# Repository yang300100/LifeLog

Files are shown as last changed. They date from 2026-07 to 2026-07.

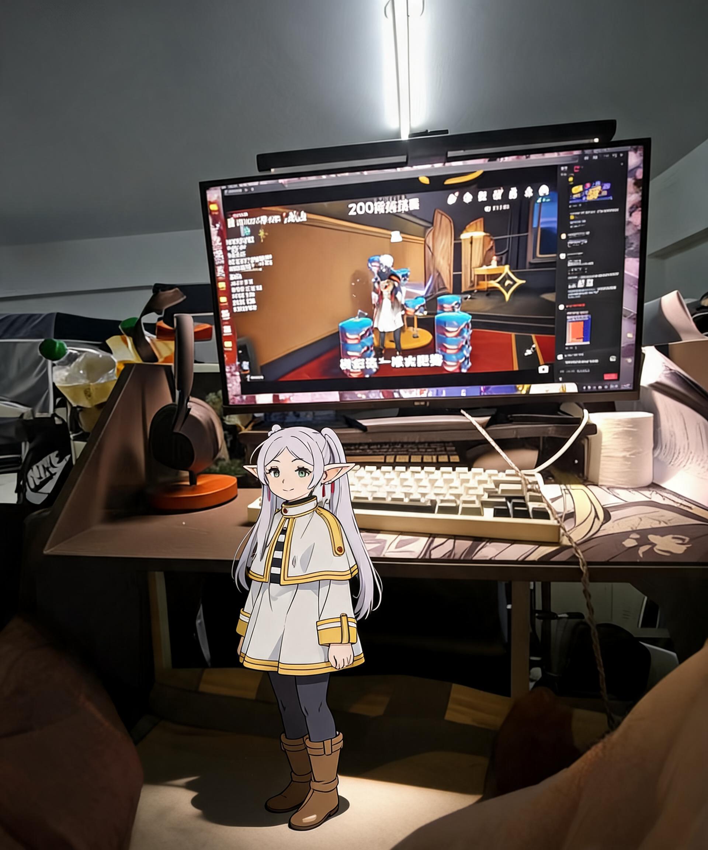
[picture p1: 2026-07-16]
prototype/e2e_output/final_result_20260630_160802.png

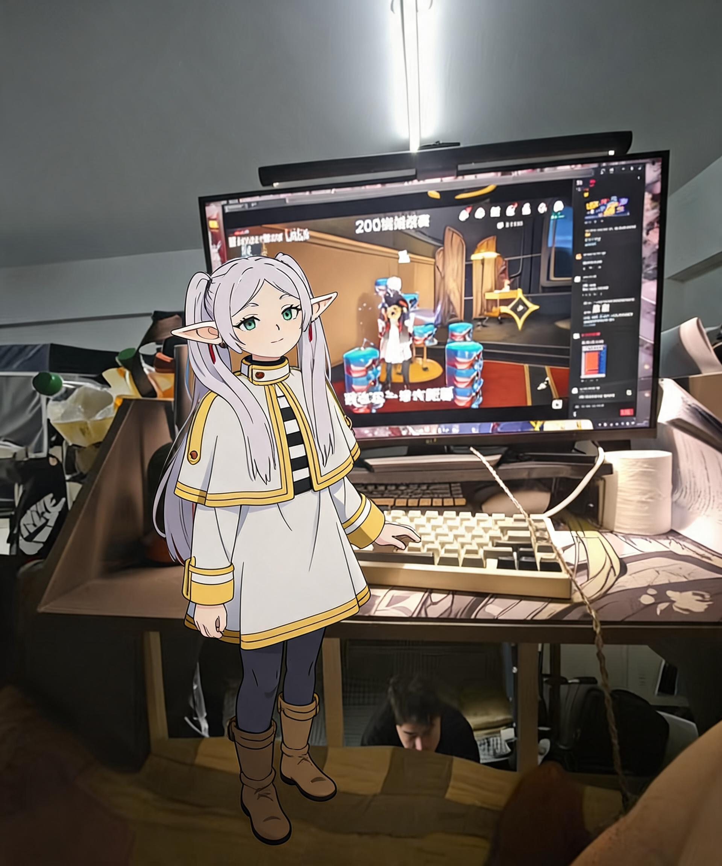
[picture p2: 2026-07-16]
prototype/e2e_output/final_result_20260630_160603.png

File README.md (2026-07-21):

# LifeLog

一款可穿戴的别针式生活记录摄像头。定时拍摄短视频片段，通过 BLE 同步到 Android 手机，利用云端 AI 分析行为并生成自然语言日报。同时提供 AI 陪伴模式，支持个性化风格照片生成。

A wearable lifelog camera in a brooch form factor. Captures short video clips at regular intervals, syncs to an Android phone via BLE, and generates natural-language daily journals using cloud AI — including an AI Companion mode for personalized stylized photo generation.

## 系统架构 / Architecture

```
ESP32-CAM （固件）             Android App               云端 AI
+------------------+       +-------------------+       +----------+
| OV3660 摄像头     |       | BLE 同步服务       |       | Kimi API |
| MJPEG 录制        | --BLE--> 文件接收          | --HTTP--> （文本）  |
| SD 卡存储         |       | 时间轴 UI          |       | Seedream |
| Deep Sleep + 踢狗  |       | AI 分析引擎        |       | （图像）  |
+------------------+       | 陪伴模式           |       +----------+
                           | 存储管理           |
                           +-------------------+
                                  |
                           +-------------------+
                           | YOLOv8n (NCNN)    |
                           | 端侧人像分割        |
                           +-------------------+
```

## 核心功能 / Key Features

- **定时拍摄 / Interval Capture** -- ESP32-CAM + OV3660 定时录制 MJPEG 视频片段（默认 QXGA 2048×1536，5 秒，5 分钟间隔）。
- **日期时间文件名 / Date-Time Filenames** -- 手机同步时间基准后，视频文件名自动使用录制日期时间（如 `20260721_143025.mjpg`），无需依赖序号。
- **BLE 文件传输 / BLE File Transfer** -- 窗口化 GATT 推送 + GATT Read 回退，支持断点续传和分页文件列表。
- **AI 日报生成 / AI Daily Reports** -- 全帧提取 → 分批发送 → Kimi API 视觉分析 → 结构化自然语言日报。
- **AI 陪伴模式 / AI Companion Mode** -- 端侧 YOLOv8n 分割检测人物，调用 Seedream API 进行局部重绘，将用户融入风格化场景。
- **RPG 实时模式 / RPG Realtime Mode** -- 基于角色的互动模式，实时活动记录与 AI 驱动叙事响应。
- **存储管理 / Storage Management** -- 按日期查看存储占用，单独/按天/全部删除视频源文件，保留数据库记录和分析结果。
- **3D 打印外壳 / 3D Printed Enclosure** -- OpenSCAD 设计的定制外壳，带挂绳孔，支持标准 FDM 打印机。

## 仓库结构 / Repository Structure

```
firmware/lifelog/         ESP32-CAM 固件 (Arduino / C++)
    lifelog.ino             主程序，含状态机 + PB0A 踢狗 + 时间同步
    camera.cpp/h            OV3660 拍摄与 MJPEG 编码
    sd_storage.cpp/h        SD 卡读写、日期文件名生成、文件索引
    ble_service.cpp/h       NimBLE GATT 服务端、窗口化文件传输
    configuration.cpp/h     运行时设置持久化（锐度/对比度/饱和度等）
    timebase.cpp/h          时间基准管理（手机同步 → 本地计时）
    config.h                编译期功能开关、踢狗间隔、默认参数
    camera_pins.h           AI-Thinker ESP32-CAM 引脚映射

android/                  Android App (Kotlin / Jetpack Compose)
    app/src/main/java/com/lifelog/camera/
        ai/                 AI 分析、分批发送、关键帧提取、陪伴流水线
        ble/                BLE 文件同步客户端、设备配置同步
        data/               Room 数据库、存储统计、数据仓库
        di/                 Hilt 依赖注入模块
        ui/timeline/        时间轴主页 & 陪伴画廊
        ui/report/          日报生成与查看
        ui/realtime/        RPG 角色实时模式
        ui/settings/        API 配置、设备设置、存储管理
        util/               崩溃日志、图像工具

enclosure/                OpenSCAD 外壳设计
    Lifelog_Case.scad       3D 打印两片式外壳

prototype/                Python 探索性脚本
    YOLO 分割、Seedream 融合测试、
    陪伴流水线原型验证
```

## 硬件规格 / Hardware

| 组件 / Component | 规格 / Specification |
|---|---|
| MCU | ESP32 (AI-Thinker ESP32-CAM) |
| 摄像头 / Camera | OV3660 (2048×1536 QXGA MJPEG) 或 OV2640 (1600×1200 UXGA) |
| 存储 / Storage | MicroSD 卡 (1-bit SD 模式) |
| 电池 / Battery | 3.7V 800mAh 锂聚合物 (402030) |
| 电源模块 / Power | PB0A 充放电一体模块（充电 + 升压5V + 电池保护 + 轻载自动断电） |
| 外壳 / Enclosure | 3D 打印 PLA/PETG，45x60x15mm |

### 接线说明 / Wiring

```
PB0A 模块           ESP32-CAM
  5V  ───────────→  5V
  GND ───────────→  GND
  BAT+ ─────────→  电池红线
  BAT- ─────────→  电池黑线
```

仅需 4 根线，全部使用成品模块，零贴片焊接。PB0A 模块通过 USB-C 充电（兼容 C-to-C 线缆），自带 4 级电量指示。

### PB0A 踢狗机制 / PB0A Keep-Alive

PB0A 充放电芯片会在负载电流 < 50mA 持续 > 32 秒时自动断电。Deep Sleep 时 ESP32 仅 4-6mA，会触发断电。

解决方案：每 25 秒唤醒一次 ESP32（启动电流 ~70mA 踢回 PB0A 计时器），踢狗唤醒时仅做最小化启动（串口 + 200ms 延迟），不初始化 SD/摄像头/BLE，功耗极低。

### 引脚约束 / Pin Constraints

- **GPIO4** -- 与 SD 卡 DATA1 冲突，LED 闪光灯永久禁用。
- **GPIO12** -- Strapping pin，启动时必须保持低电平或浮空。
- **GPIO33** -- 板载红色 LED（低电平点亮）+ 电池 ADC 分时复用。
- Deep Sleep 电流约 4-6mA（含 PB0A 升压模块静态功耗）。

## 固件编译 / Firmware Build

在 Arduino IDE 2.x 中打开 `firmware/lifelog/` 项目。

- **开发板 / Board**: AI-Thinker ESP32-CAM
- **分区方案 / Partition Scheme**: No OTA (Large APP) -- 至少 3MB 程序空间
- **波特率 / Baud Rate**: 115200
- **依赖库 / Required Libraries**: `esp_camera` (Espressif Systems)、NimBLE

### 编译开关 / Build Flags

在 `config.h` 中定义：

| 开关 / Flag | 用途 / Purpose |
|---|---|
| `WITH_SLEEP` | 拍摄间隔期间进入 Deep Sleep 省电 |
| `WITH_BLE` | 启用 BLE 广播与 GATT 文件传输 |
| `WITH_VIDEO` | 启用 MJPEG 视频录制到 SD 卡 |
| `WITH_STATUS_LED` | 启用 GPIO33 状态指示灯 |
| `WITH_AUTO_FLASH` | 暗光自动闪光灯（AEC 曝光行数阈值） |

**有意禁用的开关**: `WITH_FLASH`、`WITH_SD_4BIT`、`WITH_CAM_PWDN`、`WITH_SETUP_MODE_BUTTON`、`WITH_EVIL_CAM_PWR_SHUTDOWN`（简化硬件无需外部 MOSFET）。

### 可配置参数 / Configurable Parameters

通过 Android App 设置页面远程配置，写入 SD 卡 `camera.cfg`，下周期生效：

| 参数 / Parameter | 默认值 / Default | 范围 / Range |
|---|---|---|
| 拍摄间隔 / Interval | 300s (5min) | 60s - 3600s |
| 视频时长 / Duration | 5s | 1s - 30s |
| 分辨率 / Resolution | QXGA (2048×1536) | QVGA - QXGA |
| JPEG 质量 / Quality | 12 | 10 - 30 |
| 帧率 / FPS | 3 | 1 - 10 |
| 锐度 / Sharpness | +1 | -2 ~ +2 |
| 对比度 / Contrast | 0 | -2 ~ +2 |
| 饱和度 / Saturation | 0 | -2 ~ +2 |
| 闪光灯阈值 / Flash Threshold | 150 行 | 50 - 300 |
| BLE 广播窗口 / BLE Timeout | 30s | 30s - 600s |
| BLE 设备名 / Device Name | lifelog-cam | 最长 30 字符 |

### 烧录步骤 / Flashing

1. 连接 USB 转 TTL 适配器：RX-TX、TX-RX、GND-GND、5V-5V。
2. 将 IO0 与 GND 短接进入下载模式。
3. 上电，从 Arduino IDE 上传。
4. 移除 IO0-GND 短接，按复位键运行。

## Android App 编译 / Android App Build

在 Android Studio 中打开 `android/` 目录。

- **最低 SDK / Min SDK**: 26 (Android 8.0)
- **目标 SDK / Target SDK**: 34
- **NDK**: 30.0.14904198 (arm64-v8a)
- **主要依赖 / Key Dependencies**: Jetpack Compose, Hilt, Room, OkHttp, NCNN (native)

```bash
cd android
./gradlew assembleDebug
```

## 配置 / Configuration

首次开机时若 SD 卡无配置文件，设备进入设置模式并持续 BLE 广播，通过 Android App 进行配置。

### 时间同步 / Time Sync

ESP32 无实时时钟。每次手机 BLE 连接时自动发送当前本地时间给固件，固件据此计算 `时间基准 = 手机时间 - 开机计时器`。录制时用 `基准 + 计时器` 反算真实录制时刻，生成日期时间文件名。

RES/断电后 RTC 内存丢失，固件启动时先跑一个 30 秒 BLE 窗口获取最新时间。

### 存储管理 / Storage Management

设置 → 存储管理：按日期查看视频源文件占用，可单独/按天/全部删除 .mjpg 和 .mp4 文件。数据库记录、AI 分析结果、RPG 角色数据不受影响。

On first boot without a configuration file on the SD card, the device enters setup mode and broadcasts BLE continuously. Use the Android app to configure the parameters above.

## AI 后端 / AI Backend

Android App 支持在设置中配置多种 AI 后端：

| 用途 / Use | 后端 / Backend | 说明 / Notes |
|---|---|---|
| 文本分析 / Text Analysis | Kimi API | OpenAI 兼容接口，用于场景分析、日报生成、陪伴提示词 |
| 图像生成 / Image Generation | Seedream API | 用于陪伴模式的局部重绘 |
| 端侧推理 / On-Device | YOLOv8n (NCNN) | 陪伴流水线中的人像分割 |

API 密钥和接口地址在 App 运行时通过设置界面配置，存储在 Android SharedPreferences 中，源代码不含任何密钥。

API keys and endpoint URLs are configured at runtime via the app settings and stored in Android SharedPreferences. No keys are included in the source code.

## 开源协议 / License

本项目仅供个人使用，保留所有权利。

This project is for personal use. All rights reserved.

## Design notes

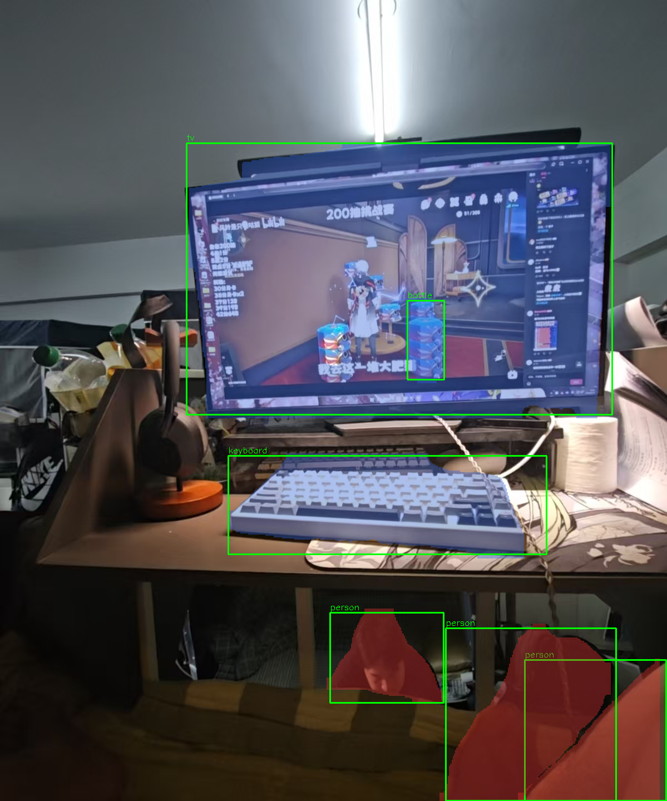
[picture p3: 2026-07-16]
prototype/e2e_output/yolo_seg_20260630_160802.png

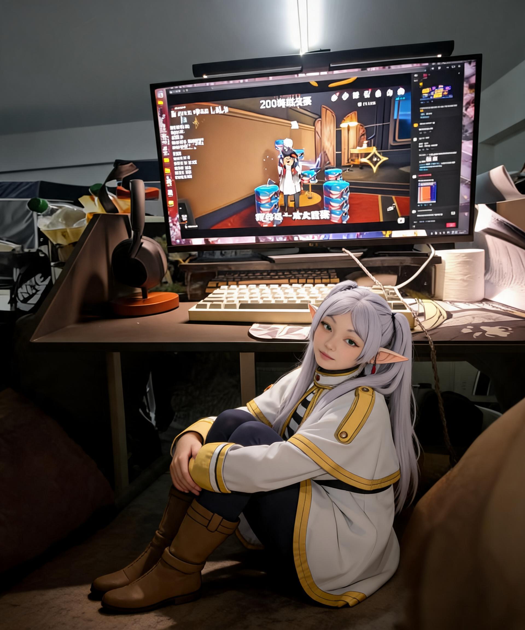
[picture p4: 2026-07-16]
prototype/seedream_output/showcase_B_sitting_area_20260630_154001.png

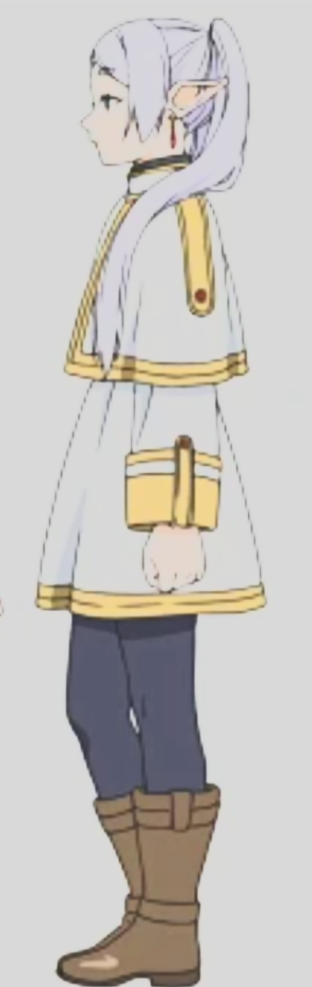
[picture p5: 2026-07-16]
prototype/ref_desktop_02.png

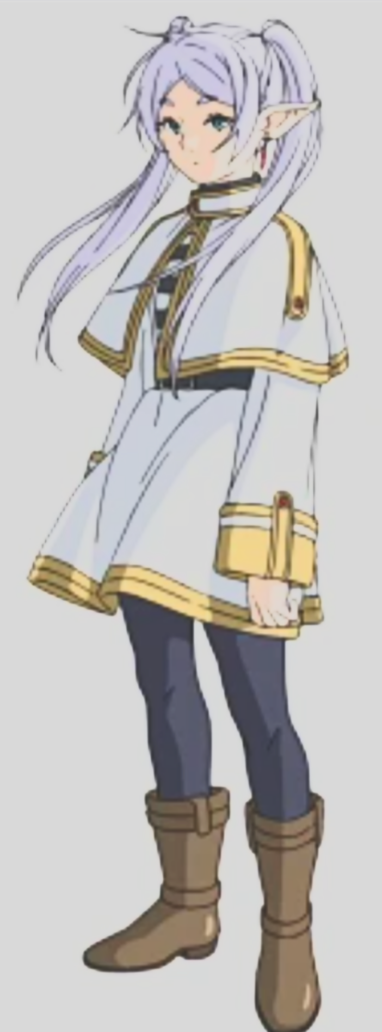
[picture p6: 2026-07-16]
prototype/ref_03.png

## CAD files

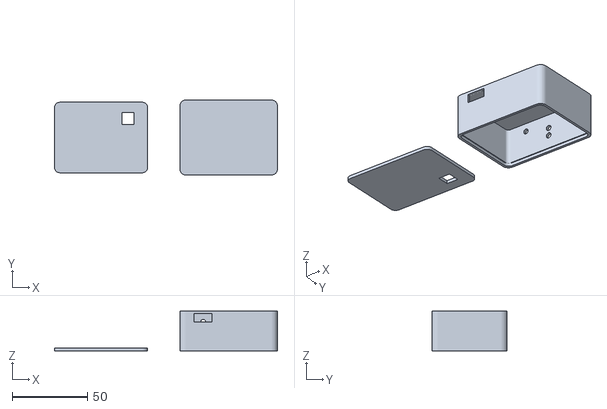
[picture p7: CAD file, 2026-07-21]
enclosure/Lifelog_Case_v2.stl
148.5 x 50.0 x 26.6

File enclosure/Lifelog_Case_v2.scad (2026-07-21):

// LifeLog Camera 外壳 v2
// 硬件: 电池(长36宽27高22) + ESP32(长43宽27高23)
// 按钮: 3mm, 位于电池顶部; USB-C: 位于电池底部

battery_w  = 27;   // 电池宽
battery_h  = 22;   // 电池高
battery_d  = 36;   // 电池长

esp32_w    = 27;   // ESP32宽
esp32_h    = 23;   // ESP32高
esp32_d    = 43;   // ESP32长

gap        = 4; clearance  = 1.5;
wall       = 1.8; round_r    = 4;

// 内部尺寸
inner_w = battery_w + gap + esp32_w + clearance * 2;  // 长61
inner_d = 23;           // 高23
inner_h = max(battery_d, esp32_d) + clearance * 2;  // 宽46

shelf_wall = 2; shelf_h = 5;
cover_ledge = 1.5; cover_d = 2;

// 外部尺寸
body_w = inner_w + 2 * shelf_wall;  // 长65
body_h = shelf_wall + inner_h + cover_d;  // 高27
body_d = inner_d + 2 * wall;         // 宽50

// 元件位置
clo = shelf_wall;
elo = clo + battery_w + gap;
cbo = shelf_wall + (inner_h - battery_h) / 2;  // 电池Y居中
ebo = shelf_wall + (inner_h - esp32_h) / 2;    // ESP32 Y居中
cdo = clearance;
edo = clearance;

cam_sz = 8;
cam_cx = elo + esp32_w / 2;
cam_top_margin = cam_sz + (shelf_h - cover_d);
cam_cy = body_h - cover_ledge - cam_top_margin - cam_sz/2;

btn_d = 3.2; btn_h = 11;
btn_cx = clo + battery_w / 2;
btn_cz = cdo + battery_d / 2;

usb_w = 10; usb_h = 4;
usb_cx = clo + battery_w / 2;
usb_cz = cdo + battery_d / 2 + 2.6;

lanyard_d = 3.5; lanyard_num = 2; lanyard_sp = 5;
lanyard_at_x = body_w / 2;
lanyard_at_z = body_d / 2;
lanyard_dir = "z";

cover_w = body_w - 2 * cover_ledge;
cover_h = body_h - 2 * cover_ledge;
cover_r = round_r - 0.5;

module rb(w, h, d, r) {
    hull() for(x=[r, w-r]) for(y=[r, h-r])
        translate([x, y, 0]) cylinder(r=r, h=d, $fn=32);
}

module front_shell() {
    difference() {
        color("LightSteelBlue", 0.9)
        translate([cover_ledge, cover_ledge, 0])
            rb(cover_w, cover_h, cover_d, cover_r);
        translate([cam_cx, cam_cy, -1])
            cube([cam_sz, cam_sz, cover_d + 2]);  // 去掉center=true, 从Z=-1贯穿到Z=3
    }
}

module back_shell() {
    bd = body_d;
    difference() {
        color("LightSlateGray", 0.9) rb(body_w, body_h, bd, round_r);
        hull() {
            translate([shelf_wall, shelf_wall, cover_d])
                rb(inner_w, inner_h, 0.1, round_r - wall);
            translate([wall, wall, shelf_h])
                rb(body_w - 2*wall, body_h - 2*wall, 0.1, round_r - wall);
        }
        translate([wall, wall, shelf_h])
            rb(body_w - 2*wall, body_h - 2*wall, bd - wall - shelf_h, round_r - wall);
        translate([cover_ledge, cover_ledge, 0])
            rb(cover_w, cover_h, cover_d, cover_r);
        btn_ty = cbo + battery_h;
        btn_ch = body_h - btn_ty;
        translate([btn_cx, body_h, btn_cz])
            rotate([90, 0, 0]) cylinder(d=btn_d, h=wall + 2, $fn=48);
        translate([btn_cx, btn_ty, btn_cz])
            rotate([90, 0, 0])
                difference() {
                    cylinder(d=btn_d + 3, h=btn_ch, $fn=48);
                    translate([0, 0, -1])
                        cylinder(d=btn_d, h=btn_ch + 2, $fn=48);
                }
        translate([usb_cx, wall + (wall + 3)/2, usb_cz])
            cube([usb_w, wall + 3, usb_h], center=true);
        translate([usb_cx, wall - 2, usb_cz])
            cube([usb_w + 2, 4, usb_h + 1.5], center=true);
        if (lanyard_num == 1) {
            translate([lanyard_at_x, body_h, lanyard_at_z])
                rotate([90, 0, 0]) cylinder(d=lanyard_d, h=wall + 2, $fn=32);
        } else {
            if (lanyard_dir == "x") {
                for (x = [lanyard_at_x - lanyard_sp/2, lanyard_at_x + lanyard_sp/2])
                    translate([x, body_h, lanyard_at_z])
                        rotate([90, 0, 0]) cylinder(d=lanyard_d, h=wall + 2, $fn=32);
            } else {
                for (z = [lanyard_at_z - lanyard_sp/2, lanyard_at_z + lanyard_sp/2])
                    translate([lanyard_at_x, body_h, z])
                        rotate([90, 0, 0]) cylinder(d=lanyard_d, h=wall + 2, $fn=32);
            }
        }
    }
}

translate([0, 0, 0]) front_shell();
translate([body_w + 20, 0, 0]) back_shell();
// front_shell();
// back_shell();

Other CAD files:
enclosure/Lifelog_Case.scad

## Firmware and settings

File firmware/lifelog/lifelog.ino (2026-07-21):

// LifeLog Camera — 随身行为记录摄像头固件
//
// 状态机:
//   冷启动 → 检测 SD 卡配置文件
//     ├── 无 camera.cfg → 设置模式 (BLE 持续广播，等手机配置)
//     └── 有 camera.cfg → 正常循环:
//           Wake → Init Camera → Capture Video → SD 存储
//           → BLE 广播窗口 → Camera Off → Deep Sleep
//
// Phase 1+2: 录制循环 + BLE GATT 文件传输

#include "config.h"
#include "camera_pins.h"
#include "camera.h"
#include "sd_storage.h"
#include "configuration.h"
#include "ble_service.h"
#include "timebase.h"
#include "SD_MMC.h"
#include "esp_sleep.h"
#include "esp_timer.h"
#include "driver/rtc_io.h"
#include "driver/gpio.h"
#include <stdio.h>

// ── 板载状态 LED ──
// ESP32-CAM 红色 LED（GPIO33）：低电平点亮（阴极接 GPIO，阳极接 3.3V）
#ifdef WITH_STATUS_LED
void led_on()  { pinMode(33, OUTPUT); digitalWrite(33, LOW);  }  // LOW = 亮
void led_off() { pinMode(33, OUTPUT); digitalWrite(33, HIGH); }  // HIGH = 灭
void led_init() {
    gpio_set_direction(GPIO_NUM_33, GPIO_MODE_OUTPUT);
    gpio_set_level(GPIO_NUM_33, HIGH);  // 初始灭
}
#else
void led_on()  {}
void led_off() {}
void led_init() {}
#endif

// RTC 内存变量 — Deep Sleep 唤醒后保留
RTC_DATA_ATTR uint32_t boot_count = 0;
RTC_DATA_ATTR uint32_t restart_count = 0;  // 防止无限重启循环
RTC_DATA_ATTR uint8_t  kicks_remaining = 0; // PB0A 踢狗剩余次数（0=正常录制）
RTC_DATA_ATTR uint32_t rtc_expected_sleep_ms = 0; // 本次期望休眠时长（ms），醒来后补偿时间基准
RTC_DATA_ATTR uint64_t rtc_esp_before_sleep = 0;  // 休眠前 esp_timer ms，用于计算实际前进量

AppConfig g_cfg;

// ── 踢狗版 Deep Sleep ──
// PB0A 充放电芯片：负载 < 50mA 持续 > 32s 自动断电。
// Deep Sleep 时 ESP32 只吃 4-6mA → 会被 PB0A 断电。
// 解决方案：空闲 > 30s 时，分段睡眠（每 25s 唤醒一次），
// 启动时的 ~70mA 电流脉冲把 PB0A 的 32s 计时器踢回去。
static void enter_deep_sleep() {
    uint32_t elapsed = millis();  // 本次启动已用时间
    uint32_t interval = g_cfg.interval;

    // 计算空闲时间
    uint32_t idle_ms;
    if (interval > elapsed) {
        idle_ms = interval - elapsed;
    } else {
        // 本次耗时超过了间隔（BLE 连太久等极端情况），至少睡 1 秒
        idle_ms = 1000;
    }

    // 释放摄像头资源
    camera_power_off();
    delay(200);  // SD 缓存落盘
    SD_MMC.end();

    // 记录休眠前状态（醒来后 timebase 用这两个值判断是否需要补偿）
    rtc_expected_sleep_ms = idle_ms;
    rtc_esp_before_sleep = (uint64_t)(esp_timer_get_time() / 1000);

    if (idle_ms <= KICK_MIN_IDLE_MS) {
        // 空闲短，PB0A 32s 计时器不会触发，直接睡满
        Serial.printf("[SLEEP] 空闲 %u ms ≤ 30s, 不踢狗, 直接睡\n", idle_ms);
        esp_sleep_enable_timer_wakeup((uint64_t)idle_ms * 1000ULL);
        kicks_remaining = 0;
    } else {
        // 空闲长，需要分段踢狗
        uint8_t kicks = (uint8_t)(idle_ms / KICK_INTERVAL_MS);
        if (kicks > 30) kicks = 30;  // 安全帽
        kicks_remaining = kicks;
        Serial.printf("[SLEEP] 空闲 %u ms → %u 次踢狗, 间隔 %u ms\n",
                      idle_ms, kicks, KICK_INTERVAL_MS);
        esp_sleep_enable_timer_wakeup((uint64_t)KICK_INTERVAL_MS * 1000ULL);
    }

    Serial.flush();
    esp_deep_sleep_start();
}

// ── 录制并存储一段视频 ──
static bool record_clip(uint32_t clip_id) {
    char filepath[40];  // /sdcard/YYYYMMDD_HHMMSS.mjpg = 35 + \0

    // 生成文件名：通过 sd_make_filename 与 sd_next_filename 保证格式一致
    uint64_t record_epoch_ms = 0;
    if (timebase_is_valid()) record_epoch_ms = timebase_now_ms();
    else record_epoch_ms = (uint64_t)(esp_timer_get_time() / 1000);
    sd_make_filename(clip_id, record_epoch_ms, filepath, sizeof(filepath));

    led_on();  // 录制中红灯常亮
    Serial.printf("[REC] 录制 %s (%u ms @ %u fps)...\n",
                  filepath, g_cfg.video_duration, g_cfg.video_fps);

    int frames = camera_capture_video(filepath,
                                      g_cfg.video_duration,
                                      g_cfg.video_fps);

    if (frames < 0) {
        Serial.printf("[ERR] 录制失败 code=%d，删除残缺文件\n", frames);
        remove(filepath);
        return false;
    }

    Serial.printf("[REC] 完成: %d 帧\n", frames);
    led_off();

    // 写入 ID→时间戳 映射（供 sd_next_filename 反查日期文件名 + BLE age 计算）
    if (record_epoch_ms > 0) {
        sd_clip_ts_write(clip_id, record_epoch_ms);
        Serial.printf("[TS-WRITE] clip_%06u → %s\n",
                      clip_id, filepath + 8);  // 跳过 "/sdcard/" (8字符)
    } else {
        // 无时间基准：仍用 esp_timer 记录相对时刻（BLE 列表需要 age 字段）
        uint64_t now_ms = (uint64_t)(esp_timer_get_time() / 1000);
        sd_clip_ts_write(clip_id, now_ms);
        Serial.printf("[TS-WRITE] clip_%06u → esp_timer=%llu ms\n",
                      clip_id, (unsigned long long)now_ms);
    }

    // 更新 SD 卡索引
    if (!sd_index_update_last_id(clip_id)) {
        Serial.println("[ERR] 更新 index.txt 失败");
        return false;
    }

    return true;
}

// ── 设置模式 ──
static void enter_setup_mode() {
    Serial.println("[SETUP] 首次启动 — 自动生成默认配置...");

    config_save("/sdcard/camera.cfg", g_cfg);
    Serial.println("[SETUP] 已生成默认 camera.cfg");
    Serial.printf("[SETUP] 2 秒后开始正常循环...\n");
    delay(2000);
}

// ── 一次性清理旧文件 ──
static void cleanup_old_files() {
    // 检查清理标记文件，已清理过则跳过
    FILE *flag = fopen("/sdcard/.cleanup_done", "r");
    if (flag) { fclose(flag); return; }

    Serial.println("[CLEAN] 检测到首次启动，清理 SD 卡旧文件...");
    // 删除所有旧 clip 文件
    for (uint32_t id = 1; id <= 100; id++) {
        char fname[40];
        sd_next_filename(id, fname, sizeof(fname));
        if (remove(fname) == 0) {
            Serial.printf("  已删除: %s\n", fname);
        }
    }
    // 重置索引
    remove("/sdcard/index.txt");
    remove("/sdcard/camera.cfg");
    remove("/sdcard/clip_ts.txt");
    // 写入清理标记
    flag = fopen("/sdcard/.cleanup_done", "w");
    if (flag) { fprintf(flag, "1\n"); fclose(flag); }
    Serial.println("[CLEAN] 清理完成!");
}

// ── 主设置 ──
void setup() {
    Serial.begin(115200);
    delay(100);  // 等待串口稳定

    boot_count++;

    // ── 🐶 PB0A 踢狗检测 ──
    // 这是踢狗唤醒（不是正常录制）→ 只做最小化启动，不碰 SD/摄像头/BLE
    if (kicks_remaining > 0) {
        Serial.printf("[KICK] 踢狗唤醒 %d/%d\n", kicks_remaining, kicks_remaining + 1);
        kicks_remaining--;
        delay(200);  // 稳定电流 ~70mA，让 PB0A 看清负载脉冲
        if (kicks_remaining > 0) {
            // 还有踢狗任务 → 继续睡
            esp_sleep_enable_timer_wakeup((uint64_t)KICK_INTERVAL_MS * 1000ULL);
            Serial.flush();
            esp_deep_sleep_start();
        }
        // kicks_remaining == 0 → 踢完了，继续往下走正常录制
    }

    led_init();
    Serial.println();
    Serial.println("╔══════════════════════════════╗");
    Serial.println("║   LifeLog Camera v1.0       ║");
    Serial.println("╚══════════════════════════════╝");
    Serial.printf("  启动次数: %u\n", boot_count);

    // 1. 初始化 SD 卡
    Serial.print("[INIT] SD 卡... ");
    if (!sd_init()) {
        Serial.println("失败! 重试一次...");
        delay(500);
        if (!sd_init()) {
            Serial.println("SD 卡初始化失败，进入 Deep Sleep 60 秒后重试");
            esp_sleep_enable_timer_wakeup(60 * 1000000ULL);
            esp_deep_sleep_start();
            return;  // unreachable
        }
    }
    Serial.println("OK");
    Serial.printf("       剩余空间: %u MB\n", sd_free_mb());

    // 1.5 一次性清理旧 resolution 的大文件
    cleanup_old_files();

    // 2. 加载配置（文件不存在时自动使用默认值）
    if (!config_load("/sdcard/camera.cfg", g_cfg)) {
        // 首次启动，自动生成默认配置
        enter_setup_mode();
    }

    Serial.printf("[CFG] 模式=%s, 间隔=%us, 视频=%ums, Q=%u, 分辨率=%s, fps=%u\n",
                  g_cfg.capture_mode,
                  g_cfg.interval / 1000,
                  g_cfg.video_duration,
                  g_cfg.video_quality,
                  camera_framesize_name(g_cfg.video_resolution),
                  g_cfg.video_fps);
    Serial.printf("[CFG] 锐度=%d 对比度=%d 饱和度=%d 闪灯阈值=%u行 广播=%us 设备名=%s\n",
                  (int)g_cfg.sharpness,
                  (int)g_cfg.contrast,
                  (int)g_cfg.saturation,
                  g_cfg.flash_threshold,
                  g_cfg.ble_advertise_timeout / 1000,
                  g_cfg.ble_device_name);

    // 3. Deep Sleep 时间补偿：esp_timer 在某些芯片上休眠期间暂停，
    //    比对期望时长和实际前进量，只补差值（避免双重计数）
    if (rtc_expected_sleep_ms > 0) {
        timebase_adjust_for_sleep(rtc_expected_sleep_ms, rtc_esp_before_sleep);
        rtc_expected_sleep_ms = 0;
        rtc_esp_before_sleep = 0;
    }

    // 4. 初始化时间基准（RTC 内存保留 → 决定文件名是否带日期）
    bool had_timebase = timebase_init();

#ifdef WITH_BLE
    // 3.5 时间基准无效时，先快速连一次手机获取时间（仅每天首次开机 / RES 后）
    if (!had_timebase) {
        Serial.println("[TIME] 无有效时间基准，等待手机同步时间（30 秒窗口）...");
        // 短超时 BLE：手机连上来同步时间+文件，到点就继续
        ble_request_time(30000);
    }
#endif

    // 4. 初始化摄像头（按配置参数）
    Serial.print("[INIT] 摄像头... ");
    if (!camera_init(g_cfg)) {
        Serial.println("失败!");
        Serial.println("60 秒后重试...");
        SD_MMC.end();
        esp_sleep_enable_timer_wakeup(60 * 1000000ULL);
        esp_deep_sleep_start();
        return;
    }
    Serial.println("OK");

    // 5. 获取下一个视频编号
    uint32_t last_id = 0, last_synced = 0;
    sd_index_read(&last_id, &last_synced);
    uint32_t next_id = last_id + 1;
    Serial.printf("[IDX] 下一个视频: clip_%06u.mjpg (已录:%u, 已同步:%u)\n",
                  next_id, last_id, last_synced);

    // 6. 录制视频
    if (!record_clip(next_id)) {
        Serial.println("[ERR] 录制环节失败");
    }

    // 6.5 录制完成后关闭摄像头，释放 PSRAM 给 BLE 使用
    Serial.println("[CAM] 释放摄像头资源...");
    camera_power_off();

    // 7. BLE 广播窗口 — 等待手机连接并同步文件
#ifdef WITH_BLE
    Serial.printf("[BLE] 广播窗口 %u 秒, 设备名: %s\n",
                  g_cfg.ble_advertise_timeout / 1000,
                  g_cfg.ble_device_name);
    // BLE 会话（公告时 LED 闪烁、连接后常亮，ble_service 内部处理）
    bool synced = ble_run_sync_session(g_cfg.ble_advertise_timeout);
    led_off();
    if (synced) {
        Serial.printf("[BLE] 同步完成, 传输 %d 块\n", ble_files_transferred());
    } else {
        Serial.println("[BLE] 超时无连接，数据保留在 SD 卡");
    }
#endif

    // 8. 进入 Deep Sleep
    enter_deep_sleep();
}

void loop() {
    // 安全网：检查唤醒原因，正常情况下不会到达这里
    esp_sleep_wakeup_cause_t cause = esp_sleep_get_wakeup_cause();
    const char *causeName = "UNKNOWN";
    switch (cause) {
        case ESP_SLEEP_WAKEUP_TIMER:   causeName = "TIMER";   break;
        case ESP_SLEEP_WAKEUP_EXT0:    causeName = "EXT0";    break;
        case ESP_SLEEP_WAKEUP_EXT1:    causeName = "EXT1";    break;
        case ESP_SLEEP_WAKEUP_TOUCHPAD:causeName = "TOUCH";   break;
        case ESP_SLEEP_WAKEUP_ULP:     causeName = "ULP";     break;
        default: break;
    }
    Serial.printf("[WARN] 意外到达 loop(), 唤醒源=%s, 60 秒后重试休眠\n", causeName);
    delay(1000);
    esp_sleep_enable_timer_wakeup(60 * 1000000ULL);
    esp_deep_sleep_start();
}

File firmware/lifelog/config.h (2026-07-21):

#ifndef LIFELOG_CONFIG_H
#define LIFELOG_CONFIG_H

// 摄像头型号（AI-Thinker 引脚布局，兼容 OV2640 / OV3660 两种传感器）
#define CAMERA_MODEL_AI_THINKER

// 功能开关
#define WITH_SLEEP                    // Deep Sleep 省电
// #define WITH_EVIL_CAM_PWR_SHUTDOWN // 【已废弃】简化硬件去掉 MOSFET，不再切断摄像头电源
#define WITH_BLE                      // BLE 文件传输
#define WITH_VIDEO                    // MJPEG 视频录制

// 故意不启用:
// #define WITH_FLASH                 // GPIO4 与 SD DATA1 冲突
// #define WITH_SD_4BIT              // 仅用 1-bit 模式
// #define WITH_CAM_PWDN             // 不修改 PCB
// #define WITH_SETUP_MODE_BUTTON    // 首次开机自动进入设置模式

// ── 板载指示灯与闪光灯 ──
#define WITH_STATUS_LED              // GPIO33 红色指示灯（状态反馈）
#define STATUS_LED_PIN         33    // 与电池 ADC 共用引脚，分时复用
#define WITH_AUTO_FLASH              // 光线不足时自动开启闪光灯 (GPIO4)
#define FLASH_GPIO_NUM         4     // 摄像头闪光灯 LED
#define FLASH_DARK_THRESHOLD   150    // AEC 曝光行数阈值，超过即判定为暗光（App 可覆写）

// Deep Sleep 唤醒源
#define SLEEP_WAKEUP_TIMER

// BLE 配置
#define BLE_DEVICE_NAME_DEFAULT  "lifelog-cam"
#define BLE_ADV_TIMEOUT_DEFAULT  30000   // 广播窗口 (ms) — 30s，配合 PB0A 踢狗机制
#define BLE_ADV_INTERVAL_DEFAULT 100     // 广播间隔 (ms)

// PB0A 充放电芯片防关机踢狗
// PB0A 负载 < 50mA 持续 > 32s 自动断电。Deep Sleep 时 ESP32 只吃 4-6mA，
// 因此每隔 KICK_INTERVAL_MS 唤醒一次（启动电流 ~70mA 踢回 PB0A 计时器）
#define KICK_INTERVAL_MS        25000   // 踢狗间隔 (ms)，< 32s PB0A 阈值
#define KICK_MIN_IDLE_MS        30000   // 空闲低于此值不踢狗，直接睡满（< 32s 安全）

// 视频录制默认参数
#define VIDEO_DURATION_DEFAULT   5000    // 视频时长 (ms)
#define VIDEO_RESOLUTION_DEFAULT FRAMESIZE_QXGA   // 2048×1536 — OV3660 上限（OV2640 仅支持到 UXGA）
#define VIDEO_QUALITY_DEFAULT    12      // JPEG 质量 (10-63, 越小画质越好文件越大)
#define VIDEO_FPS_DEFAULT        3       // 帧率

// 拍照间隔默认 (ms)
#define INTERVAL_DEFAULT         300000  // 5 分钟

// 电池监测（ESP32 ADC，GPIO33 在 ESP32-CAM 上常用，按实际硬件改）
#define BATTERY_ADC_PIN         33      // ADC1_CH5
#define BATTERY_ADC_ATTEN       ADC_11db  // 0~3.9V 量程
#define BATTERY_VOLTAGE_DIVIDER 2.0f    // 分压比（100k+100k = 二分之一）
#define BATTERY_MIN_VOLTAGE     3.3f    // LiPo 放电截止电压 ≈ 0%
#define BATTERY_MAX_VOLTAGE     4.2f    // LiPo 满电电压 ≈ 100%

// SD 卡
#define SD_INDEX_FILE            "/sdcard/index.txt"
#define SD_CLIP_TS_FILE          "/sdcard/clip_ts.txt"  // 每段视频的录制时刻 (esp_timer ms)

// LED 控制（lifelog.ino 定义，ble_service 也可调用）
void led_on();
void led_off();

#endif

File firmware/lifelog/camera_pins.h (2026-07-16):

// AI-Thinker ESP32-CAM 引脚定义
// 基于 esp_camera 库标准定义，移除 LED_GPIO_NUM (GPIO4 与 SD DATA1 冲突)

#define PWDN_GPIO_NUM     32
#define RESET_GPIO_NUM    -1
#define XCLK_GPIO_NUM      0
#define SIOD_GPIO_NUM     26
#define SIOC_GPIO_NUM     27

#define Y9_GPIO_NUM       35
#define Y8_GPIO_NUM       34
#define Y7_GPIO_NUM       39
#define Y6_GPIO_NUM       36
#define Y5_GPIO_NUM       21
#define Y4_GPIO_NUM       19
#define Y3_GPIO_NUM       18
#define Y2_GPIO_NUM        5
#define VSYNC_GPIO_NUM    25
#define HREF_GPIO_NUM     23
#define PCLK_GPIO_NUM     22

// 不使用 Flash LED (GPIO4 与 SD DATA1 冲突)
// #define LED_GPIO_NUM       4

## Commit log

2026-07-16 初始提交: LifeLog 项目
    - 固件代码 (firmware/)
    - 外壳设计 (enclosure/)
    - Android 应用 (android/)
    - 原型设计 (prototype/)
    - C7-3-4L 模块
    [Lifelog_Case.scad, configuration.h, partitions.csv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]
2026-07-16 保存：Bug 修复 + 编码修复 + ground map 改进
    [lifelog.ino]
2026-07-16 清理：移除未使用的导入、GROUND_CLASSES、测试文件和pycache
2026-07-16 修改了bug
2026-07-19 feat: BLE 传输可靠性 + 设置页面 + 录制时间戳 + 转码播放
    固件:
    - 窗口化 BLE pull (max_chunks 限窗, 防止 NimBLE 静默丢包)
    - GATT Read 兜底 (尾部数据块通知通道楔死时切到 Read)
    - BLE 窗口活动续期 (传输中不会因超时断连)
    - 逐文件 progress + sync_done 触发 SD 删除已同步视频
    - 录制时间戳 (esp_timer 跨 deep sleep 连续, clip_ts.txt)
    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
    [configuration.h]
2026-07-19 feat: 状态LED(低电平) + 自动闪光灯 + 分辨率下拉 + 闪光灯滑块
    - LED GPIO33 低电平驱动, 录制常亮/公告闪烁/连接常亮, 每次set前重设方向
    - 闪光灯 GPIO4 暗光检测(弃首帧+等AEC, g_cfg.flash_threshold)
    - flash_threshold默认60000, 持久化camera.cfg, App滑块20K~200K
    - 设置页分辨率 ExposedDropdownMenuBox
    - 固件TS诊断日志
    [configuration.h]
2026-07-19 perf: 亮度检测改为取两帧取较大值，减少单帧误触发
2026-07-21 v1.3: 日期文件名 + PB0A踢狗 + 存储管理 + Token分批 + 大量bug修复
    - 新增 timebase 模块: 手机同步时间基准，录制文件名使用真实日期时间
    - PB0A 踢狗: 每25s唤醒防断电，仅最小化启动
    - BLE 窗口缩至30s，配合踢狗省电
    - Camera PWDN 硬件复位防 I2C 挂死
    - ID 系统 uint16_t→uint32_t，文件名 %04u→%06u
    - 配置解析 parse_line 修复(末尾空格导致全部回退默认值)
    - RES后时间戳 age=0 修复(不复用无效时间戳)
    - BLE block header 完整32bit file_id
    - flash_threshold 验证范围修正
    Android:
    - 新增存储管理: 按日期删除视频源文件保留分析记录
    - AI分析分批发送: 每批3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
    [configuration.h, partitions.csv]
2026-07-21 移除例程/目录，加入.gitignore
    [partitions.csv]
2026-07-21 添加了外壳文件
    添加了外壳文件
    [Lifelog_Case_v2.scad, Lifelog_Case_v2.stl]
2026-07-22 feat: 画廊下载到相册 + Seedream Prompt 重构
    - 新增 MediaStoreSaver 工具，保存陪伴图到系统 Pictures/LifeLog
    - CompanionGalleryScreen 添加下载按钮（网格卡片 + 全屏预览）
    - CompanionViewModel 添加 downloadGeneration + Toast 反馈
    - Seedream Prompt 模板完全重构：写实摄影风格、侧逆光、哑光肌理、织物纹理、电影调色
    - Kimi 筛选器动作描述改为纯动作，不加情感修饰
    - Prompt 模板移除 ref_desc 和旧姿势包装，简化结构
    - 各项 UI 细节修复与清理
